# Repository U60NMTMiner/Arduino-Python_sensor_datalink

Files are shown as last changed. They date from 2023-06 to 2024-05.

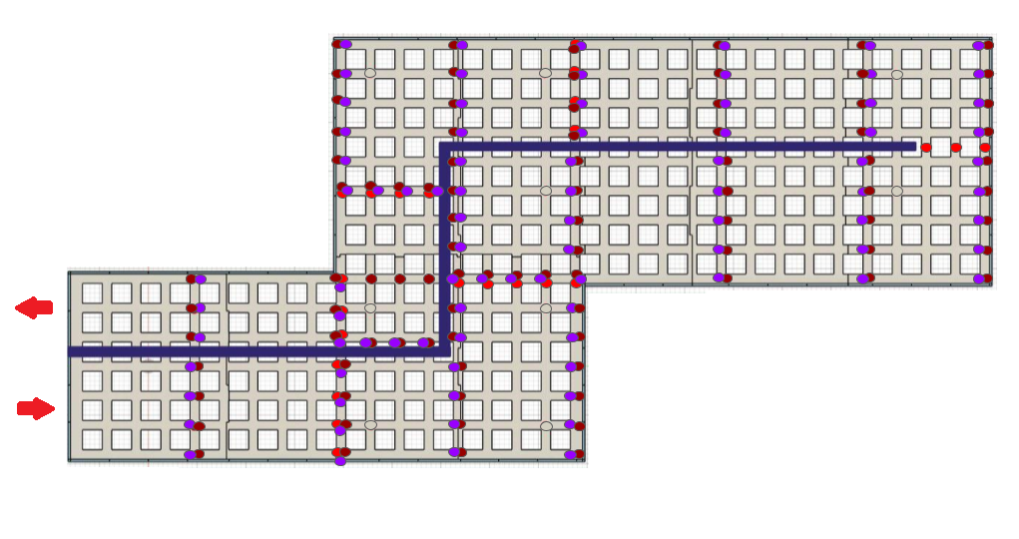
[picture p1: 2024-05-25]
Sensor_layout.png

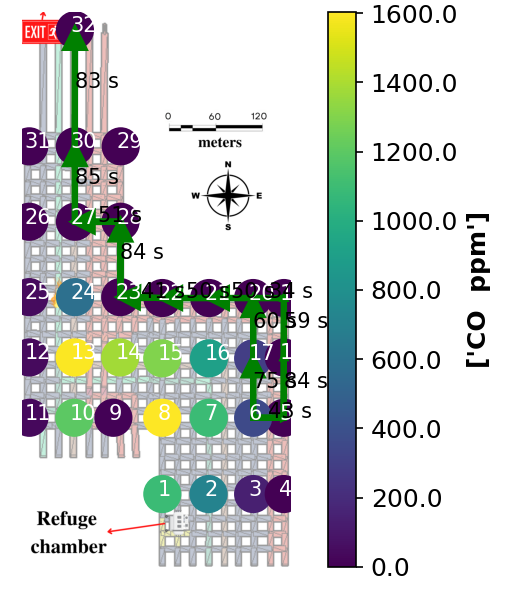
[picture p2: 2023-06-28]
ref.bmp

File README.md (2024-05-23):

# V4 System
## Overview
The latest iteration of this project, V4, has many differences from the V3 release. In order to accommodate over 200 sensors at 97 nodes, the task of collecting data is split between 3 Arduino Mega 2560 microcontrollers, an Arduino Nano microcontroller, and an Intel NUC computer. To enable communication between the devices, they are connected to a CAN ([Controller Area Network](en.wikipedia.org/wiki/CAN_bus)) bus. After collecting data from all of the sensors, the V4 Python program running on the Intel NUC sorts it into a spreadsheet. From there, the [Mine_Evacuation.py](https://github.com/sgoodyear/Arduino-Python_sensor_datalink/blob/master/Mine_Evacuation.py) program reads the spreadsheet and generates the optimal escape route. A new program, [V1_Visualizer.py](https://github.com/U60NMTMiner/Arduino-Python_sensor_datalink/blob/KorCleanup/V1_Visualizer.py), shows a color-coded map of the data extracted from the Simulation Rig.

## config.json
This configuration file has data that is used by both the V4 Serial Reader program and the new V1 Visualzer program use to run. Its main purpose is to hold huge lists of coordinates without cluttering the main programs.

The V4 Serial Reader program uses the Airspeed_..., Gas_..., and Temperature_Sensor_Coordinates to build the output data spreadsheet, and the Working_Directory and Serial_Port to configure the program on startup. The V1 Visualizer program mainly usese the Button_Coordinates to place the buttons in the user interface and relate the buttons' pixel coordinates to the sensors' physical coordinates.

## Arduino Load Splitting
With so many sensors, a single Arduino Mega does not have the available pins, memory, or processing power to collect data from all of them. Therefore, 3 Arduino Megas are being used to collect data from each of the 3 types of sensors. One Arduino is responsible for collecting data from all 23 of the air velocity sensors, one collects data from all the MQ-2 gas sensors, and one collects data from all of the AHT20 temperature sensors. Even in this arrangement, the Arduino Mega does not have enough pins to connect to all of the sensors directly. To solve this issue, each Arduino is connected to an array of multipliexers that allow one analog pin (or 1 i2c bus) to collect data from over 100 sensors.

## CAN Bus Communication
A 2-wire CAN bus is the heart of this project since it is how all 4 of the devices communicate and corrdinate data collection. To begin the process, the V4 Python program on the Intel NUC sends the "Go" signal over the CAN bus (using the Arduino Nano as an intermediate via Megabaud Binary serial) which tells all of the Arduino Mega microcontrollers to begin collecting data from all of the sensors. To help simplify the V4 Python program, the Arduinos send their data in the same order every time. To begin, the airspeed sensor Arduino sends its data over the CAN bus first (as soon as their data is collected). Since all of the Arduinos connected to the CAN bus can read all of the messagees that are sent, the Arduino connected to the MQ-2 gas sensors waits until the airspeed data termination message is broadcasted before it sends its data. Similarly, the Arduino connected to the AHT20 temperature sensors waits until the gas data termination message is broadcasted before it sends its data.

This order (Airspeed, Gas, Temperature) was chosen because of the amount of time it takes the Arduinos to collect data from each type of sensor. The airspeed is first because their Arduino only has to make 46 analog read operations (2 for each airspeed sensor), then gas requires 93 analog read operations (1 for each gas sensor), then the temperature requires 172 commands sent over the i2c bus (2 commands per sensor) plus a 40 to 80ms internal delay for each connected sensor. Since all of the Arduinos begin data collection process simultaneously, this ensures that they are ready for the next "Go" signal as quickly as possible.

As for the individual messages that each Arduino sends, each one contains an ID and 4 bytes of data. On startup, each Arduino assigns itself a unique ID character (A, S, T, and ~) based on its role. Since the maximum amount of data that can be sent in a message is 8 bytes, the float or long integer results of the sensor readings are converted into 4 bytes of binary data. Each message that is broadcasted over the CAN bus contains the data from one sensor, and after all of the messages are sent, the Arduino sends a termination signal using the termination ID (" ^ "), and using it's unique ID ("A","S", or "T") as the message. The V4 Python program will convert the data from byte form back into its orignal float form or long integer form based on the type of data it is.

### CAN Bus Example
The code used by the Arduino Nano to pass on the "Go" signal from the Raspberry Pi, using an [mcp2515.h library](https://github.com/autowp/arduino-mcp2515):
```
  canGo.can_id = 0x7E;                        // Using the master controller ID "~" in HEX
  canGo.can_dlc = 1;                          // Specify just one byte of data will be sent
  canGo.data[0] = byte("G");                  // "Go" signal
```

## Power
The data collection section of this project is powered entirely by a MeanWell 150 Watt power supply. Plugged into US wall power at 120vAC, it outpts 24vDC at up to 6.5 amps. For safety, a [3D printed cover](https://github.com/sgoodyear/Arduino-Python_sensor_datalink/blob/master/3D%20Models/Power%20Supply%20Terminal%20Cover%20v1.3mf) was added to cover up the exposed power terminals. At the output of the power supply, two xt-60 connectors and 1 deans (aka "t-plug") connector are available to split the output between
* A generic brand 24v to 12v buck converter to supply power to the airspeed sensors
* A raw 24v output

Instead of stepping 24v down to 5v at the power supply and running a 6 AWG cable to send power to the Arduinos and 5v sensors, a much smaller 12AWG cable sends 24v to several smaller buck converters to supply 5v to small groups of components. As an additional safety measure, the 24v to 12v converter has an xt-60 connector on the 24 volt side and an xt-90 connector on the 12 volt side to ensure it will not be connected backwards.

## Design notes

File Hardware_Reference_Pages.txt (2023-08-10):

150 Watt power supply: https://www.meanwell-web.com/content/files/pdfs/productPdfs/MW/LRS-150F/LRS-150F-spec.pdf
Hot Wire Airspeed sensors: https://moderndevice.com/products/wind-sensor-rev-p?variant=42521581224178, https://moderndevice.com/blogs/documentation/calibrating-the-rev-p-wind-sensor-from-a-new-regression
High Velocity 2-stage Fan: https://www.mouser.com/datasheet/2/632/GFC0412DS-DV17(REV01)-595333.pdf
AHT20 Temperature sensors: https://files.seeedstudio.com/wiki/Grove-AHT20_I2C_Industrial_Grade_Temperature_and_Humidity_Sensor/AHT20-datasheet-2020-4-16.pdf
MQ-2 Gas sensors: https://www.mouser.com/datasheet/2/321/605-00008-MQ-2-Datasheet-370464.pdf
i2c Multiplexer: https://www.adafruit.com/product/2717
Analog Multiplexer: https://www.sparkfun.com/datasheets/IC/cd74hc4067.pdf
CAN bus modules: https://lastminuteengineers.com/mcp2515-can-module-arduino-tutorial/#:~:text=TJA1050%20Datasheet-,MCP2515%20Module%20Pinout,-Now%20let%E2%80%99s%20have

DC Current wire size calculator: https://www.omnicalculator.com/physics/dc-wire-size

Sensosr layout: https://docs.google.com/presentation/d/1iU9-4sDkxN5r5blLVAVAElmQhg7pdddcT2UxLzKhD1Q/edit?usp=sharing

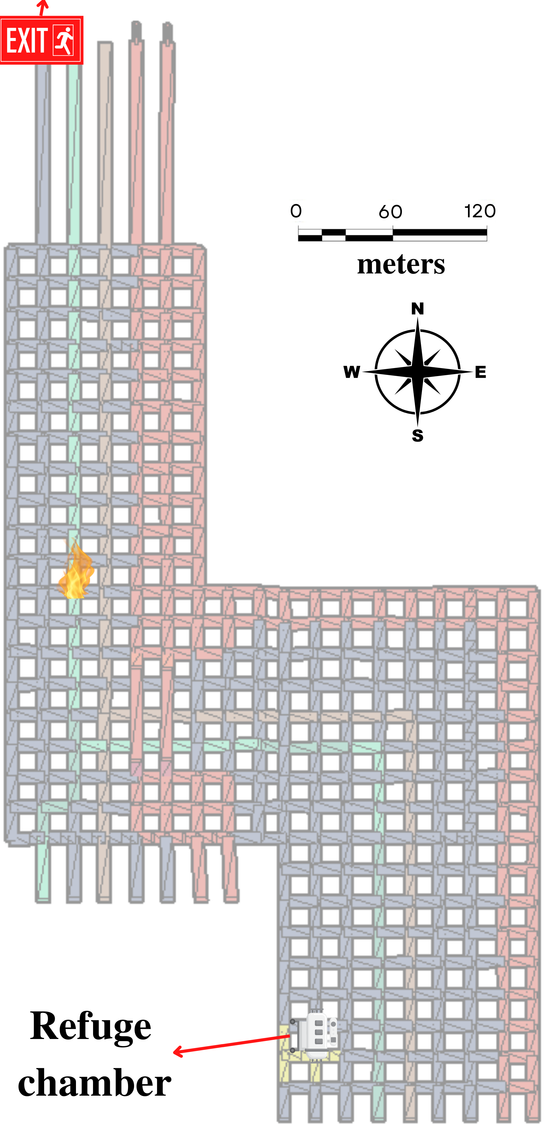
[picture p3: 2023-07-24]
CO concentration Model_3.png

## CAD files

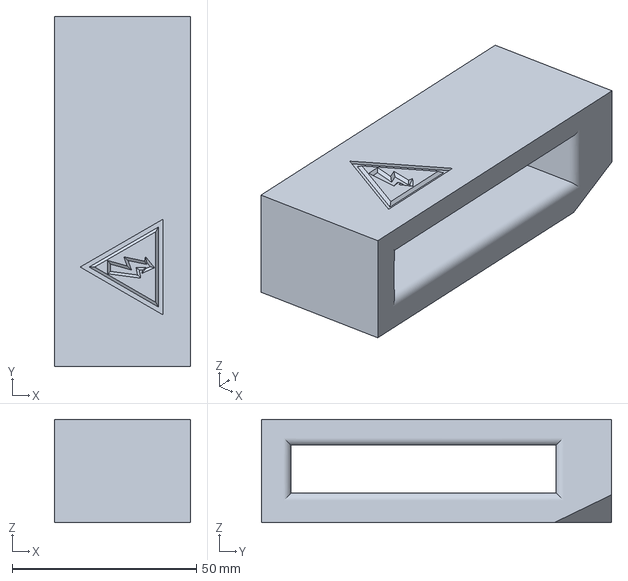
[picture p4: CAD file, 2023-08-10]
3D Models/Power Supply Terminal Cover v1.3mf
37.0 x 95.0 x 28.0 mm

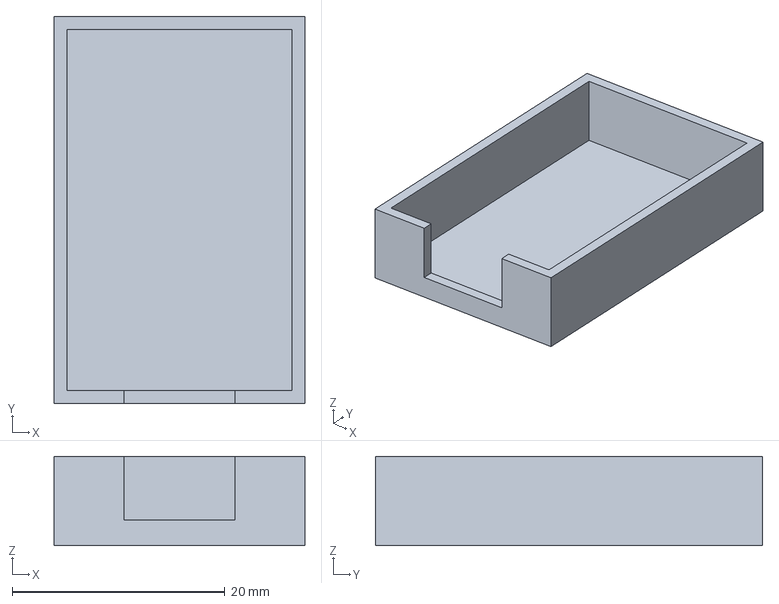
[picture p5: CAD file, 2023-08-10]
3D Models/Gas Sensor Case.3mf
23.6 x 36.4 x 8.40 mm

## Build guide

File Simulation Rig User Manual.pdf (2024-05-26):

# NMT - NIOSH Simulation Rig

## Located in MSEC 236

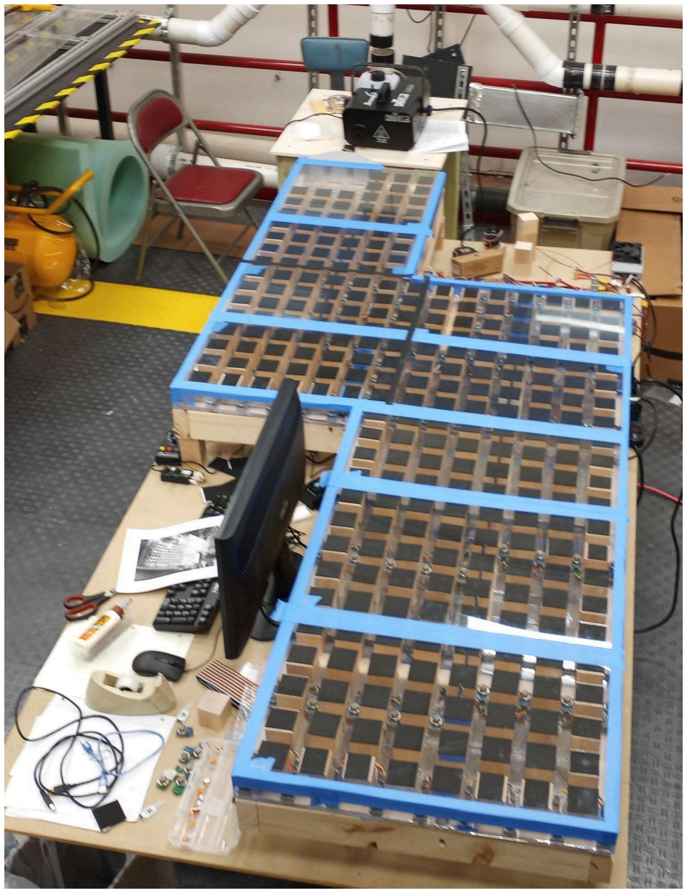
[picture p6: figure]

User Manual Version 2.00
May 2024

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
4 Intake Fan Control | 5 Smoke Machine | 6 Smoke Machine LED Codes | 6

2

# Contacts:

Supervisors:
- Dr. Hassanalian: mostafa.hassanalian@nmt.edu
- Hassan Khaniani: hassan.khaniani@nmt.edu

Student workers:
- Sean Goodyear: sean.goodyear@student.nmt.edu
- Skyler Bunning: skyler.bunning@student.nmt.edu

3

# Powering On

Assuming the Simulation Rig was correctly shut down and powered off, this procedure is used to turn everything back on.

Remember:
The computer running the Simulation Rig is shared by many people. Never use it to do anything you don’t want other people to see. This includes saving passwords, entering personal information, and downloading files.
1. Plug the surge protector (“power strip”) into the wall
2. Flip the surge protector’s switch to “reset” (or ON)
At this point, the cooling fan for the silver power supply should begin spinning
3. Power on the Intel NUC mini-computer by pressing the power button on the front
4. Log in with the password written on the sticky note on the NUC
5. Launch PyCharm using the icon in the center of the desktop
6. If the “V4_serial_reader.py” program is not already open, double click on its name in the box on the left side of the screen to open it
7. If the “V1_Visualizer.py” program is not already open, open it as well
8. Click the green play button to start the “V4_serial_reader” program, then start the “V1_Visualizer” program after waiting a few seconds.
9. Once finished with the program, single-click the red square stop button at the top of the screen to close the programs. The data is saved to a spreadsheet while the program is running, so there is almost no risk of data loss.

4

# Powering Off

Proper shut-down procedure is necessary to prevent damage to the software and electronics.

1. Close the PyCharm program and any open windows
2. From the start menu in the bottom left corner of the desktop, select “shut down”.
4. Turn off the smoke machine (see instructions in the Smoke Machine section)
5. Flip the switch on the surge protector (“power strip”) to “OFF”
All fans will stop spinning.
6. Unplug the surge protector
For storage, the surge protector can be plugged into itself.

5

# Intake Fan Control

The fan speed control box controls the rpm speed of both stages of the 2-stage intake fan. It is plugged into the surge protector for power, and it connects to the yellow + green control wires of the fan as well as the black + brown ground wires.

1. Turning a knob clockwise increases the speed of the fan stage
2. Turning a knob counterclockwise decreases the speed of the fan stage
3. The knobs are labeled “FRONT FAN” and “REAR FAN”, and control the front (‘first stage’) and rear (‘second stage’) of the fan accordingly
4. Generally, the first stage moves more air, and the second stage works best when the first stage is at an equal or greater speed setting

6

# Smoke Machine

The smoke machine generates lots of fog relative to the size of the simulation rig. Ensure the system is sealed properly before turning anything on. The smoke machine is not known to trigger the room’s smoke detector, but avoid filling the entire room with smoke.

## Caution: The smoke machine becomes hot during use, be careful not

to burn yourself.

1. After turning on the rest of the simulation rig, ensure the pink extension cord is plugged in and use the red switch on the back of the smoke machine to begin its preheating process
2. While the machine is heating, an LED illuminating the smoke fluid tank will glow red
3. Once the LED illuminating the smoke fluid tank turns blue, the machine is up to temperature
4. If the red or blue LEDs begin flashing, stop using the machine, power it off, and refill the tank with water based fog fluid. We are using FogWorx Extreme High Density fluid
5. Using the remote control, set the desired flow rate and press the red “Manual” button once to release smoke. If no smoke was produced, try increasing the flow rate. Depending on the ambient temperature, settings below 6 may not produce smoke

Avoid using the “Timer” and “Continuous” buttons, since they can easily overwhelm the intake fan, especially when it is running at low speed

6. When finished, use the switch on the back of the fog machine to power it off separately from the rest of the simulation rig and unplug the pink extension cord from the wall

## Smoke Machine LED Codes

Red:
Machine is heating. Wait for the red LED to go out before using.

Flashing Red:
Machine is heating and requires smoke fluid refill.

Blue:
Machine is at or near full temperature, ready to use.

Flashing Blue:
Machine is at or near full temperature but requires smoke fluid refill.

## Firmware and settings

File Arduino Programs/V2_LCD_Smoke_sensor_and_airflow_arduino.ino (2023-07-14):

//future misc. variable setup
int stop;
unsigned long rightnow;
unsigned long justnow;
unsigned long previousMillis = 0;
unsigned long interval = 1000;               //how often data is sent
String rightnowString;


//flammable gas sensor setup
long smk01;
long smk02;
long smk03;
long smk04;
long smk05;
long smk06;
long smk07;
long smk08;
long smk09;
long smk10;
long smk11;
long smk12;
long smk13;
long smk14;
long smk15;
long smk16;

//air sensor setup
#include <Wire.h>
byte fetch_pressure(unsigned int *p_Pressure);
#define TRUE 1
#define FALSE 0
byte _status;
unsigned int P_dat;
unsigned int T_dat;
double PR;
double TR;
double V;
double VV;
double Vcor;

int air00;

//LCD display setup
#include <LiquidCrystal.h>
const int rs = 12, en = 11, d4 = 5, d5 = 4, d6 = 3, d7 = 2;
LiquidCrystal lcd(rs, en, d4, d5, d6, d7);

void setup() {
  Serial.begin(9600);
  pinMode(53, INPUT_PULLUP);                           //pin for button to signal data collection finished

  //gas sensor setup continued
  pinMode(A0, INPUT);
  pinMode(A1, INPUT);
  pinMode(A2, INPUT);
  pinMode(A3, INPUT);
  pinMode(A4, INPUT);
  pinMode(A5, INPUT);
  pinMode(A6, INPUT);
  pinMode(A7, INPUT);
  pinMode(A8, INPUT);
  pinMode(A9, INPUT);
  pinMode(A10, INPUT);
  pinMode(A11, INPUT);
  pinMode(A12, INPUT);
  pinMode(A13, INPUT);
  pinMode(A14, INPUT);
  pinMode(A15, INPUT);

  //airflow sensor setup
  Wire.begin();
  delay(500);

  //fancy lights
  pinMode(22, OUTPUT); //green led
  pinMode(24, OUTPUT); //yellow led
  pinMode(26, OUTPUT); //red led
  digitalWrite(22, HIGH);                            //startup test to make sure no LEDs are burned out
  delay(300);
  digitalWrite(24, HIGH);
  delay(300);
  digitalWrite(26, HIGH);
  delay(300);
  digitalWrite(22, LOW);
  digitalWrite(24, LOW);
  digitalWrite(26, LOW);
  delay(300);
  digitalWrite(22, HIGH);                            //make sure the green LED stays on

  //LCD setup
  lcd.begin(16,2);
  lcd.clear();
  lcd.setCursor(0, 0);
  lcd.print("LCD TEST");
  delay(100);
  lcd.print("8888888888888888");
  lcd.setCursor(0, 1);
  lcd.print("8888888888888888");
  delay(250);
  lcd.clear();
  lcd.setCursor(0, 0);

  //Serial calibration stuff, to tell the python code how many sensors are being used

  ////////////////////////////////////MANUALLY add the names and locations of all active sensors here!!!!!//////////////////////////////////////////////////////
  //a sensor is "active" if it is sending data over serial
  Serial.println("S01 S02 S03 S04 S05 S06 S07 S08 S09 S10 S11 S12 S13 S14 S15 S16 A01");             //names of sensors go here
  Serial.println("15 28 7 19 3 12 25 31 10 21 6 30 13 24 5 9 1");                 //get node numbers from https://github.com/sgoodyear/Arduino-Python_sensor_datalink/blob/master/ref.bmp

  lcd.setCursor(0, 0);
  lcd.print("....Working....");
  lcd.setCursor(0, 1);
  lcd.print("Timestamp:");
}


void loop() {
//airflow/pressure sensors
  _status = fetch_pressure(&P_dat, &T_dat);
  switch (_status) {                              //built-in error diagnosis from airflow sensors
    case 0: //Serial.println("Ok ");
      break;
    case 1: //Serial.println("Busy");
      break;
    case 2: //Serial.println("Slate");
      break;
    default: /*Serial.println("Error");*/ digitalWrite(22, LOW); digitalWrite(26, HIGH);
      break;
  }

  rightnow = millis();

  //Serial.println(rightnow / 1000);

  PR = (double)((P_dat - 819.15) / (14744.7));        //math to calibrate airflow sensor data
  PR = (PR - 0.49060678);
  PR = abs(PR);
  V = ((PR * 13789.5144) / 1.225);
  VV = (sqrt((V)));
  Vcor = VV - 7.47;
  TR = (double)((T_dat * 0.09770395701));
  TR = TR - 50;

  ///////////////////////////////Serial outputs (to Python program)////////////////////////////////////////////////

  if (rightnow - previousMillis >= interval && rightnow != justnow) {
    previousMillis = rightnow;
      rightnowString = String(rightnow / 1000); // Convert rightnow to string

  // Pad the string with leading zeros to ensure it is always 5 digits
  while (rightnowString.length() < 5) {
    rightnowString = "0" + rightnowString;
  }
    lcd.setCursor(11, 1);
    lcd.print(rightnowString);


  //Timestamp
    //Serial.print("Ts"); Serial.print(rightnowString); Serial.print(",");
        //not currently using timestamp becasue the serial comms are already being sent in 1-sec intervals
        //  therefore, the index of the data created in python is the 'timestamp'


  //Smoke sensors
    smk01 = constrain(analogRead(A0), 250, 800);  smk01 = constrain(map(smk01, 300, 800, 0, 9000), 0, 10000);
    smk02 = constrain(analogRead(A1), 250, 800);  smk02 = constrain(map(smk02, 300, 800, 0, 9000), 0, 10000);
    smk03 = constrain(analogRead(A2), 250, 800);  smk03 = constrain(map(smk03, 300, 800, 0, 9000), 0, 10000);  //approximate conversion from sensor data to PPM reading
    smk04 = constrain(analogRead(A3), 250, 800);  smk04 = constrain(map(smk04, 300, 800, 0, 9000), 0, 10000);
    smk05 = constrain(analogRead(A4), 250, 800);  smk05 = constrain(map(smk05, 300, 800, 0, 9000), 0, 10000);
    smk06 = constrain(analogRead(A5), 250, 800);  smk06 = constrain(map(smk06, 300, 800, 0, 9000), 0, 10000);
    smk07 = constrain(analogRead(A6), 250, 800);  smk07 = constrain(map(smk07, 300, 800, 0, 9000), 0, 10000);
    smk08 = constrain(analogRead(A7), 250, 800);  smk08 = constrain(map(smk08, 300, 800, 0, 9000), 0, 10000);
    smk09 = constrain(analogRead(A8), 250, 800);  smk09 = constrain(map(smk09, 300, 800, 0, 9000), 0, 10000);
    smk10 = constrain(analogRead(A9), 250, 800);  smk10 = constrain(map(smk10, 300, 800, 0, 9000), 0, 10000);
    smk11 = constrain(analogRead(A10), 250, 800); smk11 = constrain(map(smk11, 300, 800, 0, 9000), 0, 10000);
    smk12 = constrain(analogRead(A11), 250, 800); smk12 = constrain(map(smk12, 300, 800, 0, 9000), 0, 10000);
    smk13 = constrain(analogRead(A12), 250, 800); smk13 = constrain(map(smk13, 300, 800, 0, 9000), 0, 10000);
    smk14 = constrain(analogRead(A13), 250, 800); smk14 = constrain(map(smk14, 300, 800, 0, 9000), 0, 10000);
    smk15 = constrain(analogRead(A14), 250, 800); smk15 = constrain(map(smk15, 300, 800, 0, 9000), 0, 10000);
    smk16 = constrain(analogRead(A15), 250, 800); smk16 = constrain(map(smk16, 300, 800, 0, 9000), 0, 10000);

    //serial data output format:
    //___|_____________
    //first 3 digits: sensor ID
    //everything else: data, no separating characters anywhere

    Serial.print("S01"); Serial.print(smk01); Serial.print(",");
    Serial.print("S02"); Serial.print(smk02); Serial.print(",");
    Serial.print("S03"); Serial.print(smk03); Serial.print(",");
    Serial.print("S04"); Serial.print(smk04); Serial.print(",");
    Serial.print("S05"); Serial.print(smk05); Serial.print(",");
    Serial.print("S06"); Serial.print(smk06); Serial.print(",");
    Serial.print("S07"); Serial.print(smk07); Serial.print(",");
    Serial.print("S08"); Serial.print(smk08); Serial.print(",");
    Serial.print("S09"); Serial.print(smk09); Serial.print(",");
    Serial.print("S10"); Serial.print(smk10); Serial.print(",");
    Serial.print("S11"); Serial.print(smk11); Serial.print(",");
    Serial.print("S12"); Serial.print(smk12); Serial.print(",");
    Serial.print("S13"); Serial.print(smk13); Serial.print(",");
    Serial.print("S14"); Serial.print(smk14); Serial.print(",");
    Serial.print("S15"); Serial.print(smk15); Serial.print(",");
    Serial.print("S16"); Serial.print(smk16); Serial.print(",");

  //Airflow sensors
    //Serial.print("pressure psi:"); Serial.println(PR,10);
    Serial.print("A01"); Serial.print(abs(Vcor)); Serial.print(",");


  //that one analog airflow sensor
    //air00 = analogRead(A8);                                             //optional analog airflow sensor that I found
    //Serial.print("A00"); Serial.println(air00); Serial.print(",");


  //end the serial line to prepare for the next set of data
    Serial.println();
  }

  //killswitch, dump data and create .csv
  stop = digitalRead(53);
  if (stop == LOW) {
    //Serial.println("button press");
    Serial.println("!");
    Serial.println();
    digitalWrite(22, LOW);
    lcd.clear();
    lcd.setCursor(0, 0);
    lcd.print("Done!");
    lcd.setCursor(11, 0);
    lcd.print(rightnowString);
    while (true) {                                                     //lock the Arduino into an infinite loop until reset
      stop = digitalRead(53);
      if (stop == LOW) {                                                //flashing Y + R LEDs, reminder to depress killswitch to proceed
        delay(500);
        digitalWrite(24, HIGH);
        digitalWrite(26, LOW);
        delay(500);
        digitalWrite(24, LOW);
        digitalWrite(26, HIGH);
        lcd.clear();
        lcd.setCursor(0, 0);
        lcd.print("Done!");
        lcd.setCursor(11, 0);
        lcd.print(rightnowString);
      }
      if (stop != LOW) {                                                //flashing Y, ready for user to press reset button
        delay(250);
        digitalWrite(24, HIGH);
        digitalWrite(26, LOW);
        delay(250);
        digitalWrite(24, LOW);
        lcd.setCursor(0, 1);
        lcd.print("Ready to restart");
      }
      //Serial.println("data terminated, reset arduino");
    }
  }

  justnow = rightnow;

}

//getting the data from the airspeed sensor off of the I2C data bus
byte fetch_pressure(unsigned int *p_P_dat, unsigned int *p_T_dat) {
  byte address, Press_H, Press_L, _status;
  unsigned int P_dat;
  unsigned int T_dat;
  address = 0x28;
  Wire.beginTransmission(address);
  Wire.endTransmission();
  delay(10);
  Wire.requestFrom((int)address, (int) 4); //Request 4 bytes need 4 bytes are read
  Press_H = Wire.read();
  Press_L = Wire.read();
  byte Temp_H = Wire.read();
  byte  Temp_L = Wire.read();
  Wire.endTransmission();
  _status = (Press_H >> 6) & 0x03;
  Press_H = Press_H & 0x3f;
  P_dat = (((unsigned int)Press_H) << 8) | Press_L;
  *p_P_dat = P_dat;
  Temp_L = (Temp_L >> 5);
  T_dat = (((unsigned int)Temp_H) << 3) | Temp_L;
  *p_T_dat = T_dat;
  return (_status);
}

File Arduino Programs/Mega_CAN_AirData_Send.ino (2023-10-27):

#include <SPI.h>
#include <mcp2515.h>
#include <CD74HC4067.h>

struct can_frame canData;   // Structure for sending data
struct can_frame canStatus; // Structure for signaling end of data
struct can_frame canMsg;    // Structure for incomming messages
MCP2515 mcp(53);
bool go = false;

CD74HC4067 muxC(6, 5, 4, 3);  // Telling the library where to find the analog multiplexer control pins
CD74HC4067 muxD(11, 10, 9, 8);

int rnum;
int count = 0;

float RawWind;
float AmbientTemp;
float Vref_wind = 1.25;  // Voltage that the sensor puts out when covered by a cup
                         // You may need to adjust the potentiometer if the voltage is different
float WS_MPH;
float WS_M_S;            // Variable to temporarily hold each sensor's data
float wss[23];            // Array  for storing 23 sensors' data

// Function to convert an long integer into 4 bytes
byte databytes[4];
void I2B(long value, byte* bytes) {
  // Break the integer into 4 bytes
  bytes[0] = (value >> 24) & 0xFF;
  bytes[1] = (value >> 16) & 0xFF;
  bytes[2] = (value >> 8) & 0xFF;
  bytes[3] = value & 0xFF;
}

void setup() {
  canData.can_id  = 0x41;  // This ID tag is hex for "A"
  canData.can_dlc = 4;
  canData.data[3];

  canStatus.can_id = 0x5E;   // Character "^" to define a status message
  canStatus.can_dlc = 1;
  canStatus.data[0] = canData.can_id;

  Serial.begin(1000000);
  
  mcp.reset();
  mcp.setBitrate(CAN_1000KBPS, MCP_8MHZ);
  mcp.setNormalMode();
  delay(100);

  pinMode(A0, INPUT);
  pinMode(A1, INPUT);

  for (byte i = 2; i <= 13; i ++){
    pinMode(i, OUTPUT);                                         // Set all digital control pins to outputs
  }

  digitalWrite(13, HIGH);
}

void loop() {
  if (mcp.readMessage(&canMsg) == MCP2515::ERROR_OK) {
    if (canMsg.can_id == 0x7E && canMsg.can_dlc == 2){          // Listen for startup ping from master control unit
      mcp.sendMessage(&canStatus);                              // send back status
      delay(10);
      Serial.println("ACK sent to master's ping (A)");
      Serial.println();
    }
    else if (canMsg.can_id == 0x7E && canMsg.can_dlc == 1){     // Listen for "Go" message from master control
      go = true;
      for(int i = 0; i <= 15; i ++){                            // Read data from the multiplexers first
        muxC.channel(i);                                        // Set channel # (0 -> 15)
        muxD.channel(i);
        RawWind = analogRead(A0)  * 5.0 / 1023.0;               // 5/1023 is the correction from raw data to voltage
        AmbientTemp = analogRead(A1) * 5.0 / 1023.0;
        AmbientTemp = (AmbientTemp - 0.400) / 0.0195;           // Temperatue calibration equation provided by manufacturer
        WS_MPH = constrain( pow(((RawWind - Vref_wind)/(3.038517 * (pow(AmbientTemp, 0.115157))))/0.087288,3.009364), 0, 100);  // Airspeed calibration provided by manufacturer
        if (isnan(WS_MPH)){                                     // If Vref_wind < RawWind, the above formula spits out "NaN" ("Not a Number")
          WS_MPH = 0;                                           // When this happens, replace it with 0
          //Serial.println("NaN corrected");
        }
        WS_M_S = WS_MPH * 0.44704;                              // Conversion from mph to m/s
        wss[i] = WS_MPH;                                        // Store data in array
      }

      RawWind = analogRead(A2)  * 5.0 / 1023.0;                 // Next, read the sensors connected directly
      AmbientTemp = analogRead(A3) * 5.0 / 1023.0;
      AmbientTemp = (AmbientTemp - 0.400) / 0.0195;             // Temperatue calibration equation provided by manufacturer
      WS_MPH = constrain( pow(((RawWind - Vref_wind)/(3.038517 * (pow(AmbientTemp, 0.115157))))/0.087288,3.009364), 0, 100);  // Airspeed calibration provided by manufacturer
      if (isnan(WS_MPH)){                                       // If Vref_wind < RawWind, the above formula spits out "NaN" ("Not a Number")
        WS_MPH = 0;                                             // When this happens, replace it with 0
        //Serial.println("NaN corrected");
      }
      WS_M_S = WS_MPH * 0.44704;                                // Conversion from mph to m/s
      wss[16] = WS_MPH;                                         // Store data in array

      RawWind = analogRead(A5)  * 5.0 / 1023.0;
      AmbientTemp = analogRead(A4) * 5.0 / 1023.0;
      AmbientTemp = (AmbientTemp - 0.400) / 0.0195;             // Temperatue calibration equation provided by manufacturer
      WS_MPH = constrain( pow(((RawWind - Vref_wind)/(3.038517 * (pow(AmbientTemp, 0.115157))))/0.087288,3.009364), 0, 100);  // Airspeed calibration provided by manufacturer
      if (isnan(WS_MPH)){                                       // If Vref_wind < RawWind, the above formula spits out "NaN" ("Not a Number")
        WS_MPH = 0;                                             // When this happens, replace it with 0
        //Serial.println("NaN corrected");
      }
      WS_M_S = WS_MPH * 0.44704;                                // Conversion from mph to m/s
      wss[17] = WS_MPH;                                         // Store data in array

      RawWind = analogRead(A7)  * 5.0 / 1023.0;
      AmbientTemp = analogRead(A6) * 5.0 / 1023.0;
      AmbientTemp = (AmbientTemp - 0.400) / 0.0195;             // Temperatue calibration equation provided by manufacturer
      WS_MPH = constrain( pow(((RawWind - Vref_wind)/(3.038517 * (pow(AmbientTemp, 0.115157))))/0.087288,3.009364), 0, 100);  // Airspeed calibration provided by manufacturer
      if (isnan(WS_MPH)){                                       // If Vref_wind < RawWind, the above formula spits out "NaN" ("Not a Number")
        WS_MPH = 0;                                             // When this happens, replace it with 0
        //Serial.println("NaN corrected");
      }
      WS_M_S = WS_MPH * 0.44704;                                // Conversion from mph to m/s
      wss[18] = WS_MPH;                                         // Store data in array

      RawWind = analogRead(A9)  * 5.0 / 1023.0;
      AmbientTemp = analogRead(A8) * 5.0 / 1023.0;
      AmbientTemp = (AmbientTemp - 0.400) / 0.0195;             // Temperatue calibration equation provided by manufacturer
      WS_MPH = constrain( pow(((RawWind - Vref_wind)/(3.038517 * (pow(AmbientTemp, 0.115157))))/0.087288,3.009364), 0, 100);  // Airspeed calibration provided by manufacturer
      if (isnan(WS_MPH)){                                       // If Vref_wind < RawWind, the above formula spits out "NaN" ("Not a Number")
        WS_MPH = 0;                                             // When this happens, replace it with 0
        //Serial.println("NaN corrected");
      }
      WS_M_S = WS_MPH * 0.44704;                                // Conversion from mph to m/s
      wss[19] = WS_MPH;                                         // Store data in array
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

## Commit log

2023-06-23 attempt 2
    [2023-06-23_13-30_data.csv]
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2023-06-27 Longer data file, for more rigorous testing.
    [2023-06-27_11-09_data.csv]
2023-06-28 Create V2_Smoke_sensor_and_airflow_arduino.ino
    Version 2 of the Arduino program, will send time-indexed data instead of a constant stream
2023-06-28 it doesn't work yet
    [arduino_serial_reader_to_excel.py]
2023-06-28 data properly formatted to run the Mine_Evacuation.py analysis program
    [M_E_DataTemplate.xlsx]
2023-06-28 Add files via upload
    Reference for which sensor nodes correspond to what points in the simulation rig
2023-07-05 Sample data
    [2023-07-05_12-41_data.xlsxmod.xlsx, duplicate.xlsx]
2023-07-06 Create V2_LCD_Smoke_sensor_and_airflow_arduino.ino
    Alternate version of V2 Arduino code that runs an LCD status display
2023-07-06 Still needs to be manually adjusted if the number/location of sensors changes, but otherwise it's all set!
2023-07-06 Extra long final result
    This file is ready to be sent to the Mine_Evacuation.py program to generate an escape route based on the data it contains!
    [duplicate.xlsx]
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2023-07-18 File reorganization
    [2023-06-23_13-30_data.csv, 2023-06-27_11-09_data.csv, 2023-07-05_12-41_data.xlsxmod.xlsx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]
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2023-07-20 Plots all 14 temperature readouts on a "separate" graph, temperature sensors graphed using for-loop, reduced time from 500s to 300s to reduce latency
2023-07-26 Update V3_serial_reader_to_excel.py
    Exported data should now show timestamps in 5 second intervals to match latest V3 Arduino program
2023-08-01 Create Mega_CAN_Receive.ino
    Listens to the 1MHz CAN bus and reports what it hears over serial. Additionally, if it hears the CAN master controller send the 2-byte "r?" signal, it will respond by sending it's status message.
2023-08-02 Create Nano_CAN_Transcieve
    Code for an Arduino Nano, which will be the CAN Master Controller. On startup, it sends its ping message over CAN to determine which of the Arduino Megas are properly connected and in a 'ready' state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
2023-08-02 Create Mega_CAN_Send.ino
    This code is for an Arduino Mega to send a 256 test messages over the CAN bus very quickly. Good for testing the limits of the bus and testing delay intervals between individual messages. This code i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
2023-08-02 Create Mega_CAN_SendTemperature.ino
    Code for an Arduino Mega set up with the AHT20 i2c temperature sensors. It broadcasts the data from each sensor over the CAN bus every [interval] milliseconds. The interval is currently set to 3000ms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
    Additionally, this is configured to respond to the ping message from the CAN Master Controller.
2023-08-03 Create Mega_CAN_SmokeData_Send.ino
    Reads up to 96 MQ-2 smoke/gas sensors using an array of 6 analog multiplexers. Will eventually transmit data over CAN bus.
    Additionally, will respond to a ping from the CAN Master Controller by sending it's status message.
2023-08-03 Create Nano_CAN_Master_Controller.ino
    Interfaces between the Python program running on the Raspberry Pi control device and the CAN bus with the Arduinos. This program sends a ping on startup to determine which devices are connected, and 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
2023-08-03 Create Mega_CAN_AirData_Send.ino
    Reads data from a whole bunch of i2c AHT20 temperature/humidity sensors and sends it over the CAN bus.
    Responds to pings from the Master Controller and only sends data when it receives the "go" signal from the Master Controller.
2023-08-03 Update Mega_CAN_SmokeData_Send.ino
    Arduino now only sends data when it is requested by the Master Controller's "go" signal.
2023-08-03 Update Mega_CAN_TempData_Send.ino
    Arduino now only sends data when requested by the Master Controller's "go" signal.
2023-08-04 Simple program to read the data the Nano passes through and print it to the terminal.
2023-08-04 Re-copied the code, not by hand this time, and all the problems went away.
    [V4_serial_reader.py]
2023-08-08 I know what's wrong with it now, it was possible for a random arrangement of data to coincidentally match one of the three terminator symbols. Now, the terminator symbol is 5 characters long, where o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
    [V4_serial_reader.py]
2023-08-08 Fixed? function to convert binary back to numbers
    [V4_serial_reader.py]
2023-08-09 Update Mega_CAN_TempData_Send.ino
    Fixed issue where not all data was being sent, added second branch of i2c multiplexers, increased CAN transmission speed, revamped startup checks.
    [Mega_CAN_TempData_Send.ino]
2023-08-09 All data is being received properly. Code for dealing with temperature data has been updated to accommodate 128 sensors. Also changed process for requesting new data to include the amount of time it 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
2023-08-09 Now using the measured air velocity data (m/s) to calculate airflow (m^3/s) using multiplication by cross-sectional area (m^2). Data is now saved to a spreadsheet that generates a unique name every t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
    [V4_serial_reader.py]
2023-08-09 Update V4_serial_reader.py
    Corrected order of data written to spreadsheet
    [V4_serial_reader.py]
2023-08-10 Upload 3D files
    3D files to improve the parts used in the project.
    [Gas Sensor Case.3mf, Power Supply Terminal Cover v1.3mf]
2023-08-10 Fixed/improved terminal output text colors, added options to save spreadsheet all at once at end of program or line-by-line.
    [V4_serial_reader.py]
2023-08-11 Defined coordinate system for sensor locations, added the option to save and quit or save without quitting.
2023-09-06 Latest Data file
    [2023-08-11_12-04_data.xlsx]
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2023-12-01 Corrected expected length of incoming gas sensor data from 450 to 425.
    [V4_serial_reader.py]
2023-12-01 Fixed issue where the lists append infinitely
    [V4_serial_reader.py]
2023-12-01 Fresh example data!
    [2023-12-01_13-00_data.xlsx]
2023-12-04 Fixed(?) bug where wait_time is negative, causes time.sleep() to break.
    [V4_serial_reader.py]
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2024-01-04 Update Fan_RPM_Control.ino
    Changed pin designations to avoid using GPIO 1 and 2, which can interfere when trying to upload a new program.
    Specified which color wires go where.
    [Fan_RPM_Control.ino]
2024-02-17 Fixed program crashing after running for certain time intervals. Fixed infinitely telescoping data in the output spreadsheet. Removed blank sheet in output spreadsheet.
    [V4_serial_reader.py]
2024-02-23 Test Data with Propane Gas
    [2024-02-22_20-28_data.xlsx]
2024-02-23 Added event log to test data
    [2024-02-22_20-28_data.xlsx]
2024-02-27 New example data with gas
    [2024-02-26_18-05_data.xlsx]
2024-02-27 Uploaded event log
    [2024-02-26_18-05_data.xlsx]
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2024-04-29 Update V1_Visualizer.py
    Fixed issue where all buttons were grayed out on startup.
    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
    [V1_Visualizer.py]
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2024-05-07 Buttons placed in correct locations!
    [V1_Visualizer.py]
2024-05-08 Starting work on pulling in and formatting data from spreadsheet
    [2024-02-26_18-05_data.xlsx]
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2024-05-22 Standardized some variable names, removed unneeded commented-out code, fixed data archiving
    [V1_Visualizer.py]
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2024-05-24 It almost works! Still fixing the JSON, improved color mapping on the UI.
    [V1_Visualizer.py]
2024-05-24 Fresh data (I think the coordinates are still a little broken)
    [2024-05-24_09-45_data.xlsx, 2024-05-24_09-54_data.xlsx]
2024-05-24 Create Appended_2024-05-24_09-54_data.xlsx
    Cut so that it shows the interesting part
    [Appended_2024-05-24_09-54_data.xlsx]
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2024-05-24 Fixing node numbers in "Button_Coordinates"
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2024-05-25 Trying to fix the gas sensor data...
    [2024-05-25_16-02_data.xlsx]
2024-05-25 Still trying to fix the gas sensor data...
    [2024-05-25_16-02_data.xlsx, 2024-05-25_16-11_data.xlsx]
2024-05-26 It's working! It's really working!
    [2024-05-25_16-15_data.xlsx]
2024-05-26 One more test run
    [2024-05-25_17-31_data.xlsx]
2024-05-26 Fixed comment typo in Mega_CAN_SmokeData_Send.ino
    [Mega_CAN_SmokeData_Send.ino]
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2024-05-28 Minor changes: Changed auto-refresh interval from 2.5 seconds to 4 seconds. Fixed minor typo in serial_reader.
    [V1_Visualizer.py, V4_serial_reader.py]
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2024-09-06 Simulation rig is officially fixed!
    [Nano_CAN_Master_Controller.ino, V1_Visualizer.py, V4_serial_reader.py]
